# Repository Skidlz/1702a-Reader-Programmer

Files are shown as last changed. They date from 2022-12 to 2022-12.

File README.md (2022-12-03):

# 1702a Reader and Programmer
A DIY, arduino-based 1702a Reader and Programmer

Included are Eagle CAD schematics + board layouts, and Arduino source code

[Blog post](https://zeninstruments.blogspot.com/2020/06/diy-1702a-programmer.html)

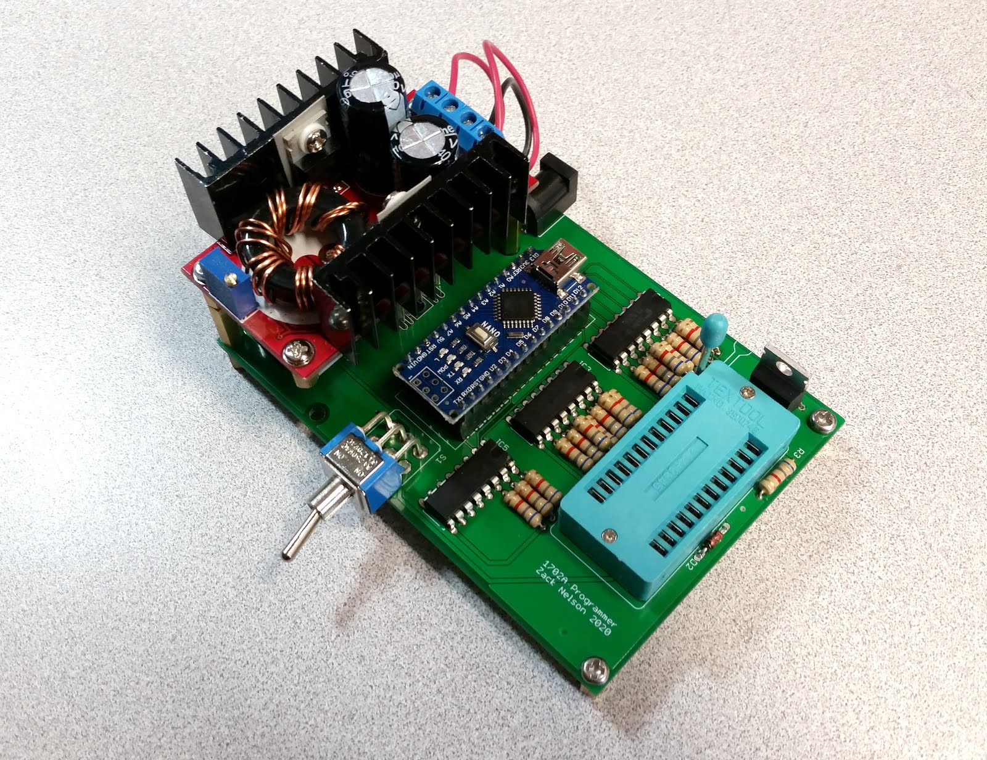
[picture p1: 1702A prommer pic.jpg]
Finished build


Prommer Schematic
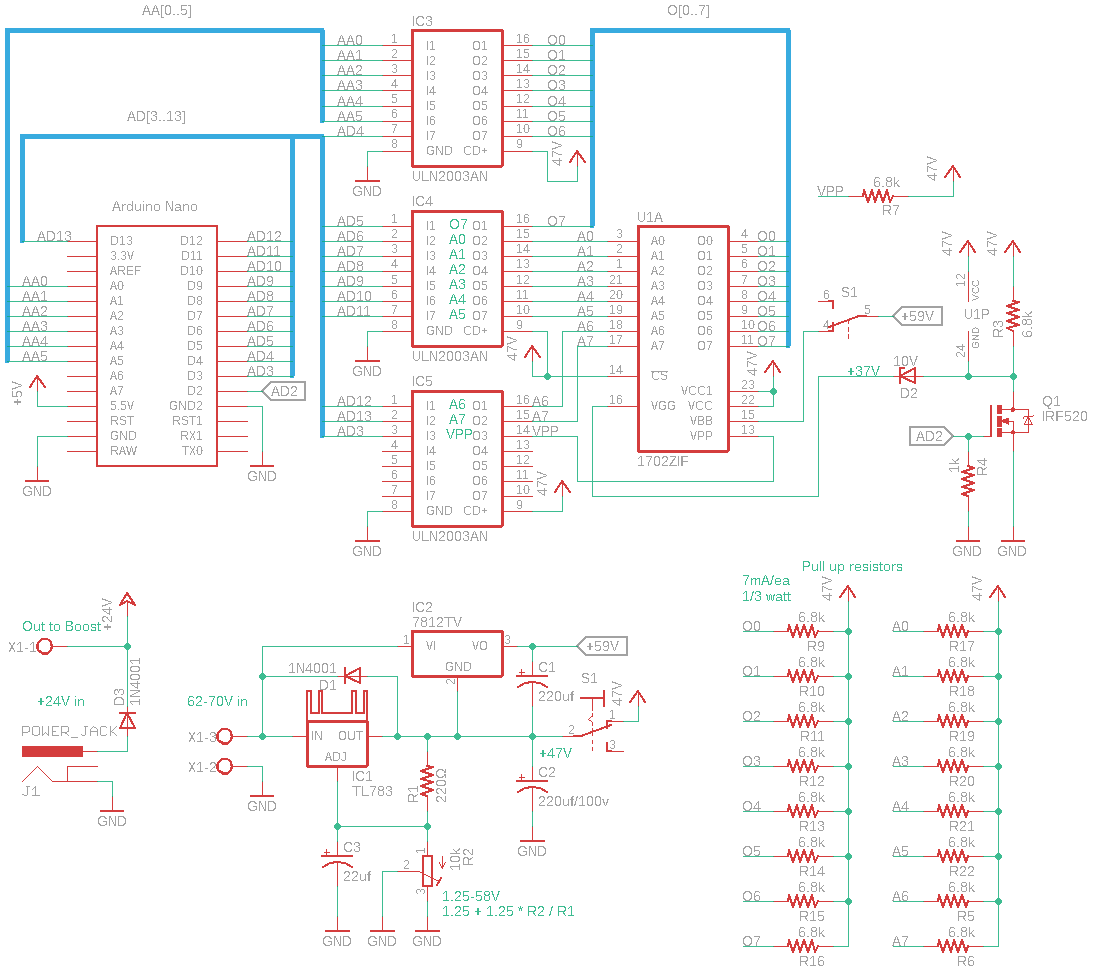
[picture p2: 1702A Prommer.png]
Prommer schematic


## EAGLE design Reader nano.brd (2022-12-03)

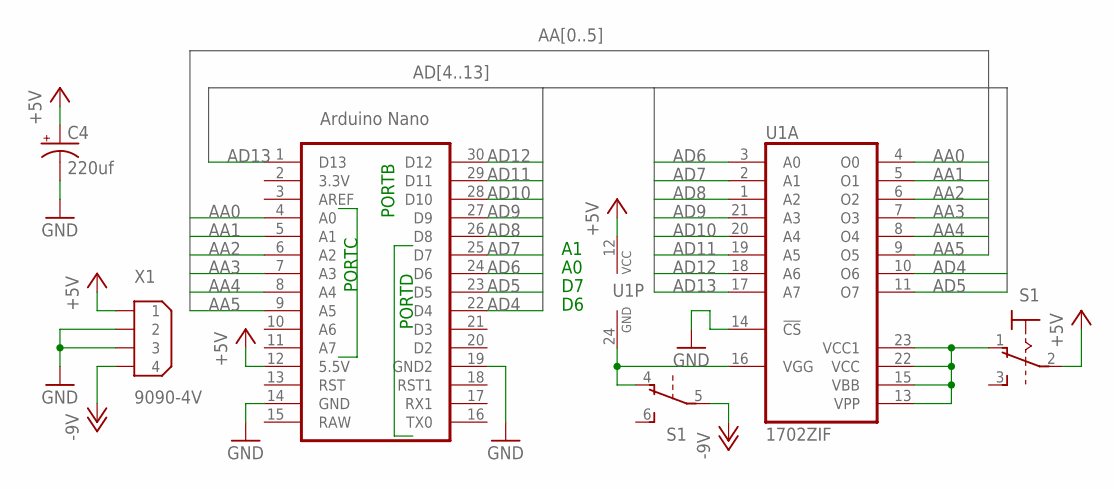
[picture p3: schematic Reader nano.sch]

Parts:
C4: 220uf; E5-10,5
S1: 320-938
U1: 1702ZIF; ZIF24
U$1: NANO
X1: 9090-4V

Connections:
+5V: C4.+, S1.2, U1.12 (VCC), U$1.12 (5.5V), X1.1
-12V: S1.5, X1.4
AA0: U1.4 (O0), U$1.4 (A0)
AA1: U1.5 (O1), U$1.5 (A1)
AA2: U1.6 (O2), U$1.6 (A2)
AA3: U1.7 (O3), U$1.7 (A3)
AA4: U1.8 (O4), U$1.8 (A4)
AA5: U1.9 (O5), U$1.9 (A5)
AD4: U1.10 (O6), U$1.22 (D4)
AD5: U1.11 (O7), U$1.23 (D5)
AD6: U1.3 (A0), U$1.24 (D6)
AD7: U1.2 (A1), U$1.25 (D7)
AD8: U1.1 (A2), U$1.26 (D8)
AD9: U1.21 (A3), U$1.27 (D9)
AD10: U1.20 (A4), U$1.28 (D10)
AD11: U1.19 (A5), U$1.29 (D11)
AD12: U1.18 (A6), U$1.30 (D12)
AD13: U1.17 (A7), U$1.1 (D13)
GND: C4.-, U1.14 (!CS), U$1.14 (GND), U$1.19 (GND2), X1.2, X1.3
unnamed: S1.1 (O), U1.13 (VPP), U1.15 (VBB), U1.22 (VCC), U1.23 (VCC1)
unnamed: S1.4 (O), U1.16 (VGG), U1.24 (GND)

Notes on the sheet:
PORTC
PORTD
PORTB

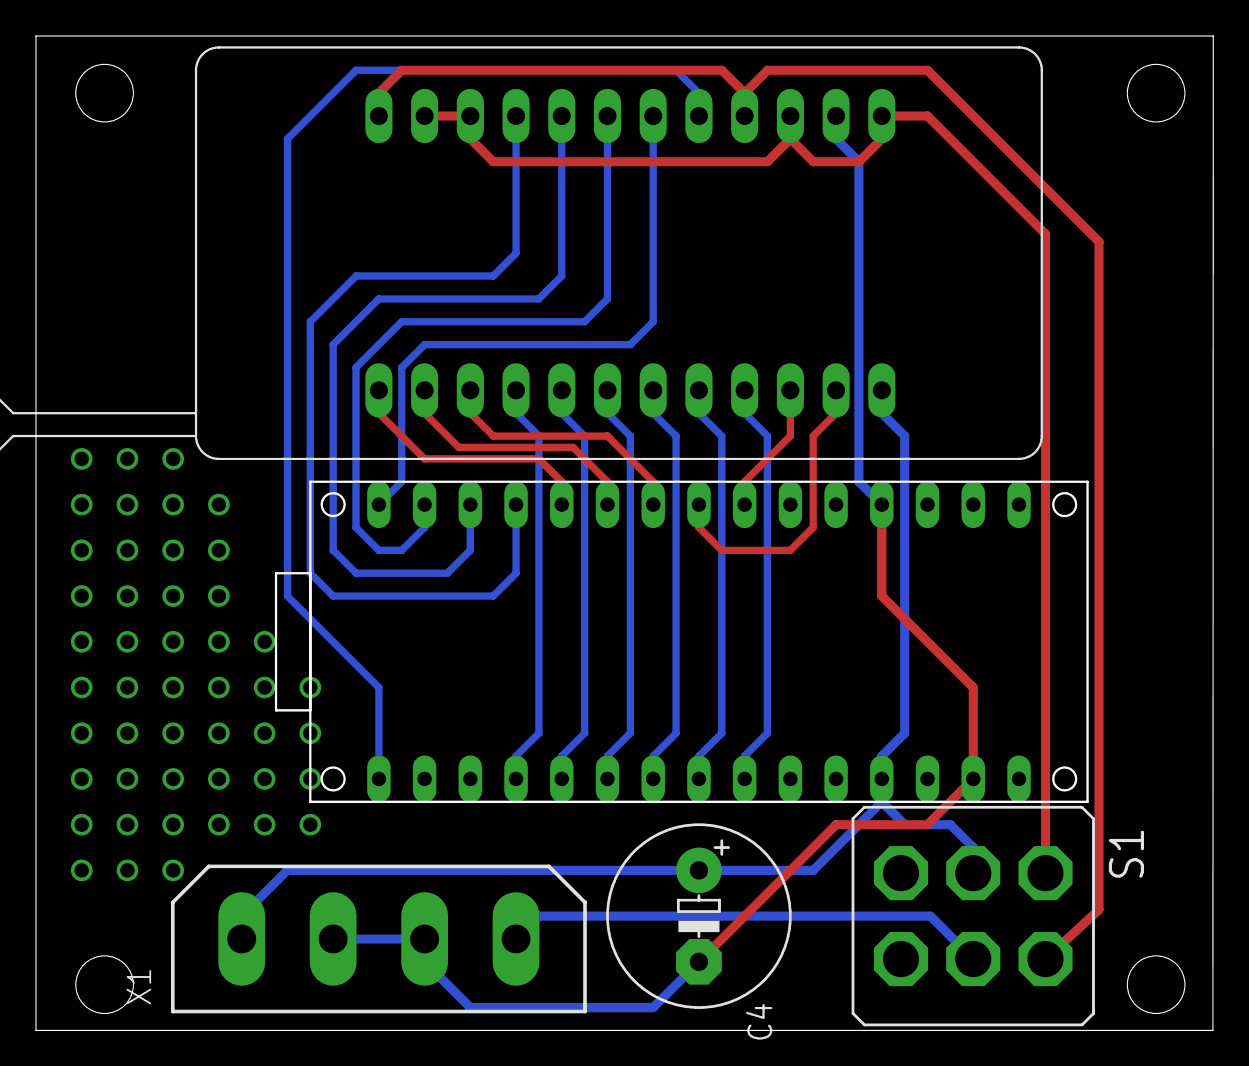
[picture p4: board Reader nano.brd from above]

Board: 2 copper layers, 65.4 x 55.2 mm, 5 parts (0 on the bottom side), 21 nets.

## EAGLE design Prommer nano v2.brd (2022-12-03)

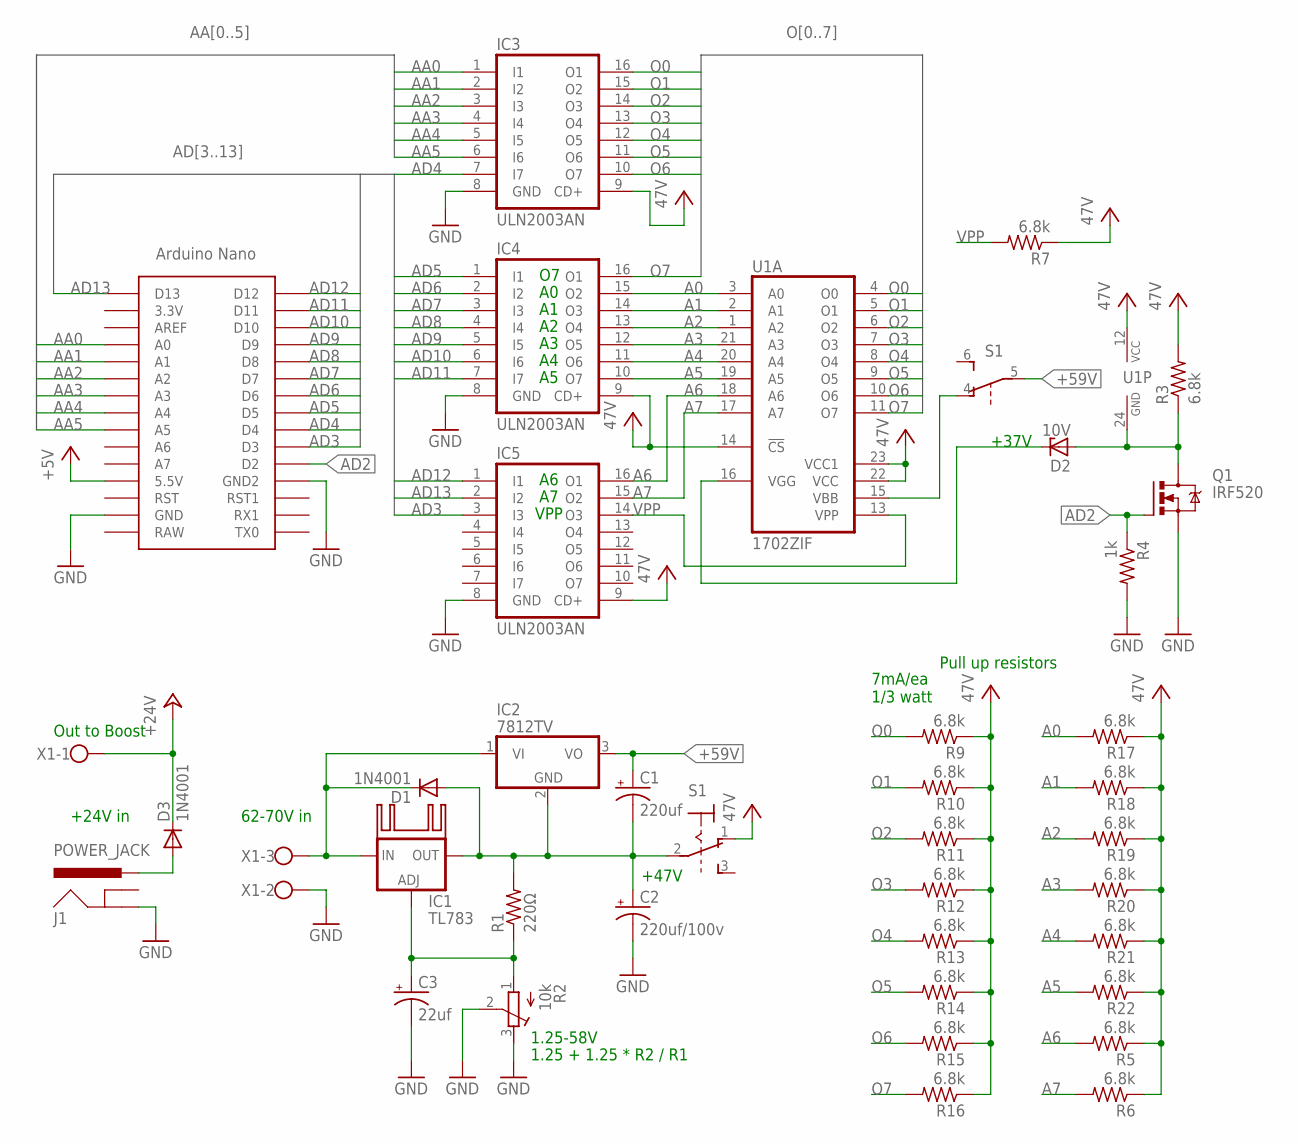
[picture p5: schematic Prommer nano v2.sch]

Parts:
C1: 220uf; E5-10,5
C2: 220uf/100v; E5-13
C3: 22uf; E5-10,5
D1, D3: 1N4001; D-7.5
D2: 10V; DO34Z7
IC1: TL783; 317TS
IC2: 7812TV; TO220V
IC3, IC4, IC5: ULN2003AN; DIL16
J1: POWER_JACK; POWER_JACK_PTH
KK1: SK95-2M3
Q1: IRF520; TO220BV
R1: 220Ω; 0207/10
R2: 10k; RTRIM64W
R3, R5, R6, R7, R9, R10, R11, R12, R13, R14, R15, R16, R17, R18, R19, R20, R21, R22: 6.8k; 0207/10
R4: 1k; 0207/10
S1: 320-938
U1: 1702ZIF; ZIF24
U$1: NANO
X1: W237-103

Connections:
+5V: U$1.5V (5.5V)
+24V: D3.C, X1.1
+47V: IC3.9 (CD+), IC4.9 (CD+), IC5.9 (CD+), R3.2, R5.1, R6.1, R7.1, R9.1, R10.1, R11.1, R12.1, R13.1, R14.1, R15.1, R16.1, R17.1, R18.1, R19.1, R20.1, R21.1, R22.1, S1.1 (O), U1.12 (VCC), U1.14 (!CS), U1.22 (VCC), U1.23 (VCC1)
+59V: C1.+, IC2.3 (VO), S1.5
A0: IC4.15 (O2), R17.2, U1.3 (A0)
A1: IC4.14 (O3), R18.2, U1.2 (A1)
A2: IC4.13 (O4), R19.2, U1.1 (A2)
A3: IC4.12 (O5), R20.2, U1.21 (A3)
A4: IC4.11 (O6), R21.2, U1.20 (A4)
A5: IC4.10 (O7), R22.2, U1.19 (A5)
A6: IC5.16 (O1), R5.2, U1.18 (A6)
A7: IC5.15 (O2), R6.2, U1.17 (A7)
AA0: IC3.1 (I1), U$1.A0
AA1: IC3.2 (I2), U$1.A1
AA2: IC3.3 (I3), U$1.A2
AA3: IC3.4 (I4), U$1.A3
AA4: IC3.5 (I5), U$1.A4
AA5: IC3.6 (I6), U$1.A5
AD2: Q1.G, R4.1, U$1.D2
AD3: IC5.3 (I3), U$1.D3
AD4: IC3.7 (I7), U$1.D4
AD5: IC4.1 (I1), U$1.D5
AD6: IC4.2 (I2), U$1.D6
AD7: IC4.3 (I3), U$1.D7
AD8: IC4.4 (I4), U$1.D8
AD9: IC4.5 (I5), U$1.D9
AD10: IC4.6 (I6), U$1.D10
AD11: IC4.7 (I7), U$1.D11
AD12: IC5.1 (I1), U$1.D12
AD13: IC5.2 (I2), U$1.D13
GND: C2.-, C3.-, IC3.8 (GND), IC4.8 (GND), IC5.8 (GND), J1.GND, Q1.S, R2.2 (S), R2.3 (E), R4.2, U$1.GND, U$1.GND1 (GND2), X1.2
unnamed: D1.C, IC1.3 (IN), IC2.1 (VI), X1.3
unnamed: C3.+, IC1.1 (ADJ), R1.1, R2.1 (A)
unnamed: D2.C, U1.16 (VGG)
unnamed: D2.A, Q1.D, R3.1, U1.24 (GND)
unnamed: C1.-, C2.+, D1.A, IC1.2 (OUT), IC2.2 (GND), R1.2, S1.2
unnamed: D3.A, J1.PWR
unnamed: S1.4 (O), U1.15 (VBB)
O0: IC3.16 (O1), R9.2, U1.4 (O0)
O1: IC3.15 (O2), R10.2, U1.5 (O1)
O2: IC3.14 (O3), R11.2, U1.6 (O2)
O3: IC3.13 (O4), R12.2, U1.7 (O3)
O4: IC3.12 (O5), R13.2, U1.8 (O4)
O5: IC3.11 (O6), R14.2, U1.9 (O5)
O6: IC3.10 (O7), R15.2, U1.10 (O6)
O7: IC4.16 (O1), R16.2, U1.11 (O7)
VPP: IC5.14 (O3), R7.2, U1.13 (VPP)

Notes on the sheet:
62-70V in
+47V
1.25-58V
1.25 + 1.25 * R2 / R1
+24V in
Out to Boost
VPP
Pull up resistors
7mA/ea 1/3 watt
+37V

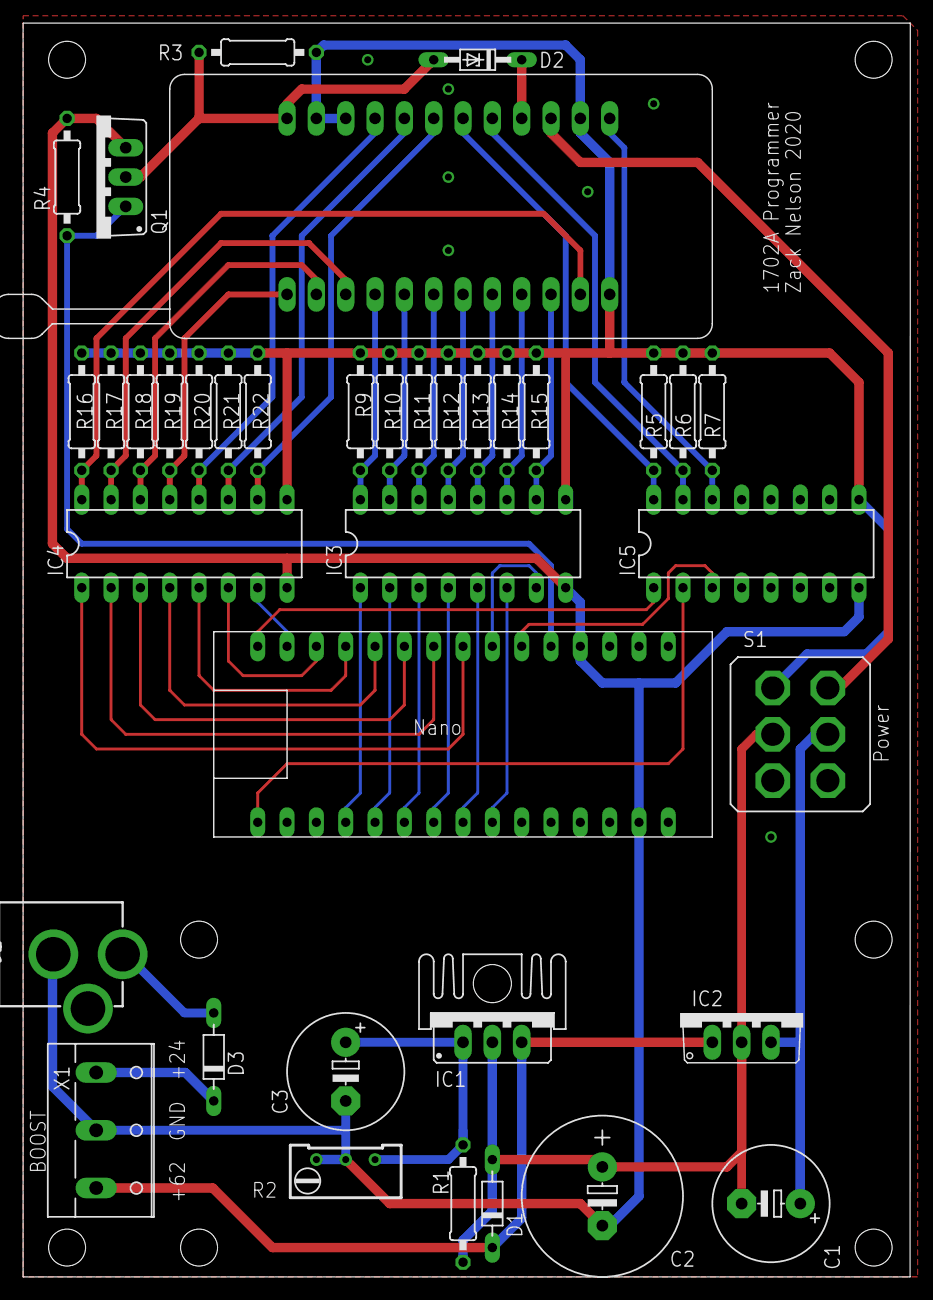
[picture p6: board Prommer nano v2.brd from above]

Board: 2 copper layers, 76.8 x 108.6 mm, 39 parts (0 on the bottom side), 46 nets.

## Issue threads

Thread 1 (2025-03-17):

Z-Diode D2 (1702a Programmer)

samson0812, 2025-03-17:
Hello,
is the Zener diode D2 shown with the correct polarity in the circuit diagram?
In my opinion, +47V at the anode doesn't result in +37V at pin 16 (VGG).

Regards, Ingolf

Closed 2025-03-17.

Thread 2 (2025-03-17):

1702a Reader and Programmer

samson0812, 2025-03-17:
Hello,
is the Zener diode D2 shown with the correct polarity in the circuit diagram?
In my opinion, +47V at the anode doesn't result in +37V at pin 16 (VGG).

Regards, Ingolf

Skidlz, 2025-03-17:
Hi Ingolf. I believe the orientation is correct, but the note of +37V is misleading/wrong. VGG will be 10V relative to ground, and VCC will be 37V relative to VGG.
I think that portion of the design came from Stephen Lafferty's programmer here: http://www.tronola.com/html/1702a_prom_programmer.html

samson0812, 2025-03-17:
Hello Skidlz,

thanks for the quick reply. I've considered your suggestion and looked at the other circuit.

It's definitely about setting VGG 10V higher than GND when programming. In this case, the

Zener diode is entered correctly.

Was it purely out of interest in the circuit, or did I need to burn a 1702?

Regards, Ingolf

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

Skidlz, 2025-03-17:
I only started this project so I could read and program 1702a PROMs for my PAiA 8700 computer. It's a DIY music computer from about 1977, and it uses 1702a's. I would have been easier to adapt some more modern EPROMs, but this is the path I chose!

samson0812, 2025-03-19:
Hello,

It's me again.

I noticed that the +5V on the EPROM (pin 12) isn't switched on the reader module, but is switched on pin 22 via S1.

But the EPROM has an internal connection from pin 12 to 22! That makes the switch inoperative, right?

Regards, Ingolf

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

Closed 2025-03-17.

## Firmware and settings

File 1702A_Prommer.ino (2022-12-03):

#define VPP 3
#define VGG 2

byte PORTB_t = 0x00;
byte PORTC_t = 0x00;
byte PORTD_t = 0x00;

byte buff[] = 
 {0x20, 0x21, 0x0D, 0x20, 0x71, 0x0D, 0x20, 0xC3, 0x0D, 0x20, 0x2B, 0x0D, 0xA5, 0xBF, 0x8D, 0x20, 
0x08, 0x20, 0x00, 0x0F, 0xC9, 0x01, 0x30, 0xE8, 0xD0, 0xE9, 0xA0, 0x5C, 0x20, 0x52, 0x0D, 0xF0, 
0xE2, 0xA9, 0x00, 0xA2, 0x28, 0xD8, 0x95, 0xBF, 0xCA, 0xD0, 0xFB, 0xA2, 0x10, 0xB5, 0xCF, 0x18, 
0x75, 0xBF, 0x8D, 0x00, 0x09, 0x9D, 0xEF, 0x09, 0x30, 0x0F, 0x09, 0x80, 0x24, 0xE8, 0x50, 0x04, 
0xD5, 0xA9, 0xF0, 0x05, 0xA4, 0xE9, 0x88, 0xD0, 0xFD, 0x95, 0xA9, 0xCA, 0xD0, 0xDF, 0xE6, 0xBF, 
0xA0, 0x00, 0xA2, 0x08, 0xAD, 0x10, 0x08, 0x30, 0xFB, 0xAD, 0x10, 0x08, 0x30, 0x0F, 0x2A, 0x10, 
0xF8, 0x6A, 0x95, 0xDF, 0xCD, 0x10, 0x08, 0xF0, 0xFB, 0xCA, 0xD0, 0xED, 0x60, 0x94, 0xDF, 0x30, 
0xF8, 0xA5, 0xEA, 0x85, 0xEB, 0xA2, 0x10, 0xB5, 0xCF, 0xF0, 0x27, 0x29, 0x7F, 0x09, 0x40, 0xA0, 
0x09, 0x88, 0xF0, 0x12, 0xD9, 0xDF, 0x00, 0xD0, 0xF8, 0x95, 0xCF, 0xC6, 0xEB, 0xF0, 0x33, 0xA9, 
0x00, 0x99, 0xDF, 0x00, 0xF0, 0x04, 0x29, 0xBF, 0x95, 0xCF, 0x24, 0xE8, 0x10, 0x01, 0xCA, 0xCA, 
0xD0, 0xD5, 0xA2, 0x10, 0xA0, 0x09, 0xA9, 0x40, 0x35, 0xCF, 0xD0, 0x0E, 0x88, 0xF0, 0x13, 0xB9, 
0xDF, 0x00, 0xF0, 0xF8, 0x95, 0xCF, 0xC6, 0xEB, 0xF0, 0x08, 0x24, 0xE8, 0x10, 0x01, 0xCA, 0xCA, 
0xD0, 0xE4, 0x60, 0xA5, 0xE8, 0x10, 0x38, 0xA2, 0x10, 0xA0, 0x40, 0xB5, 0xCF, 0x2A, 0x2A, 0xB5, 
0xCE, 0x90, 0x19, 0x10, 0x0B, 0x18, 0x65, 0xBA, 0xC9, 0xBF, 0x90, 0x1B, 0xA5, 0xBE, 0xD0, 0x17, 
0xA0, 0xC0, 0xE5, 0xBB, 0xC5, 0xBC, 0x10, 0x0F, 0xA5, 0xBC, 0x10, 0x0B, 0x38, 0x09, 0x80, 0xE5, 
0xBD, 0x30, 0x04, 0xA0, 0x00, 0xA9, 0x80, 0x94, 0xBE, 0x95, 0xCE, 0xCA, 0xCA, 0xD0, 0xCA, 0x60};

void write_data_bus(byte data){
  PORTD_t &= 0b11001111; //bits 7 & 6
  PORTD_t |= (data >> 2) & 0b110000;
  PORTC_t = data & 0b00111111; //bit 5-0
  PORTD = PORTD_t;
  PORTC = PORTC_t;
}

void set_address_bus(int address){
  PORTB_t = ~address >> 2; //bits 7-2
  PORTD_t &= 0b00111111; //bits 1 & 0
  PORTD_t |= (~address << 6) & 0b11000000;
  PORTB = PORTB_t;
  PORTD = PORTD_t;
}

void fast_write(int address, byte data){
  write_data_bus(data);   //set data bus
  set_address_bus(~address); //set comp address bus
  delayMicroseconds(40);

  bitSet(PORTD_t, VGG); //set Control VDD/VGG ON
  bitSet(PORTD, VGG); //set Control VDD/VGG ON
  delayMicroseconds(150);

  set_address_bus(address); //set address bus
  delayMicroseconds(40);
  
  bitSet(PORTD, VPP); //set Program Pulse ON
  delayMicroseconds(2700);

  bitClear(PORTD, VPP); //set Program Pulse OFF
  delayMicroseconds(40);

  bitClear(PORTD_t, VGG); //set Control VDD/VGG OFF
  bitClear(PORTD, VGG); //set Control VDD/VGG OFF
  write_data_bus(0);   //powerdown
  set_address_bus(255); //powerdown
  delay(12);
  
  //Serial.print('#'); //progress indicator
}

/************************************************
 * MAIN
 *************************************************/
void setup(){
  //IO
  DDRB = 0b00111111; //Addr 2-7
  DDRD = 0b11111110; //Addr 0-1, Data 6-7, VPP, VGG, TX, RX
  DDRC = 0b00111111; //Data 0-5

  write_data_bus(0);   //powerdown
  set_address_bus(255); //powerdown
  
  //Serial.begin(57600);  //set speed of serial connection
  delay(1000);
}

void loop(){
  int dataLength = 256;
  //fill buffer
  /*
  for(int bytes; bytes < dataLength; bytes++)if(Serial.available())buffer[bytes] = Serial.read();
  Serial.println("Received 256 Bytes\n Writing to EPROM");
  */
  //program all addresses 32 times
  for(int x = 0; x < 32; x++)for(int i = 0; i < dataLength; i++)fast_write(i,buff[i]);
  
  //Serial.println('%');
  while(1); //done
}

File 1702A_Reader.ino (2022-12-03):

void setup() {
  //IO
  DDRB = 0b00111111; //Addr 2-7
  DDRD = 0b11000010;
    //Addr 0-1, Data 6-7, NC, NC, TX, RX
  DDRC = 0b00000000; //Data 0-5
  PORTC = 0b00111111; //pull ups
  PORTD = 0b00110000; //pull up
  
  Serial.begin(9600);

  for(int i = 0; i < 256; i++) { //loop data
    if(i % 16 == 0) Serial.println();
    PORTB = i >> 2; //set addr hi
    PORTD = (i << 6) | 0b110000; //lo
    delayMicroseconds(50);
    byte data = PINC | ((PIND <<2) & 0b11000000); //data
    if (data < 16) Serial.print("0"); //leading zero
    Serial.print(data, HEX); //output byte
    Serial.print(", ");
  }
}

void loop() {
}

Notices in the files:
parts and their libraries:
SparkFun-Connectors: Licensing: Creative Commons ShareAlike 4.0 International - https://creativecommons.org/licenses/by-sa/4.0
